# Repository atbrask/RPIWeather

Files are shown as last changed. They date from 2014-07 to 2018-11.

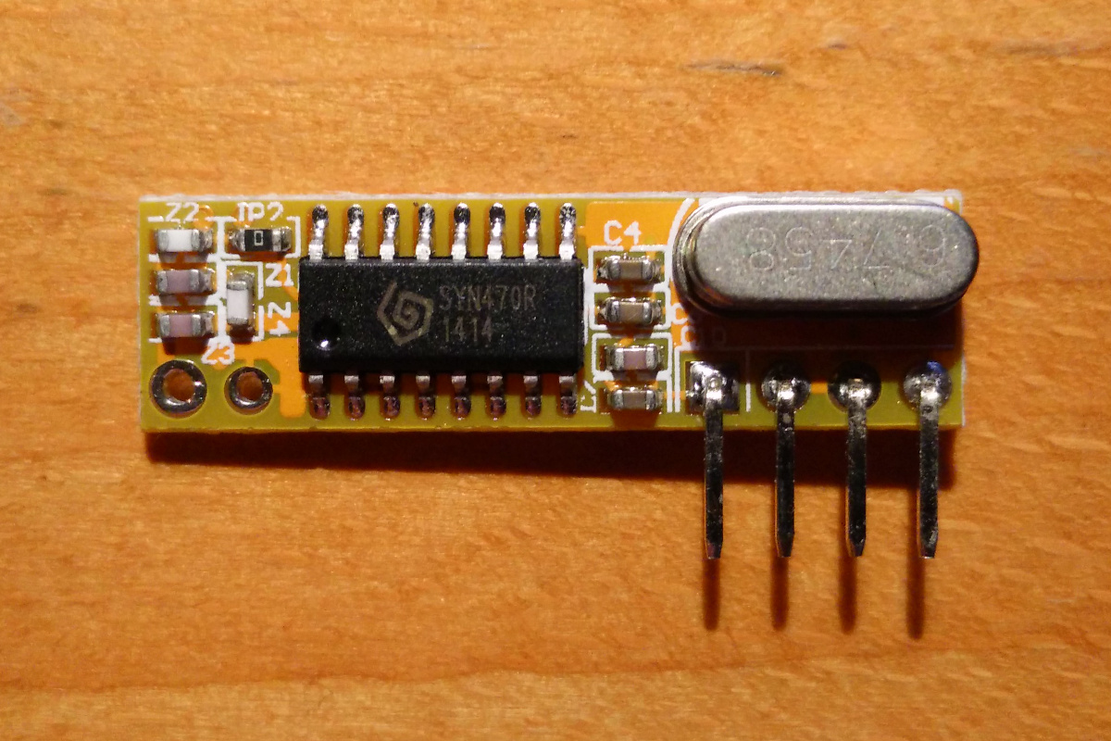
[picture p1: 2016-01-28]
Pictures/RXB12.jpg

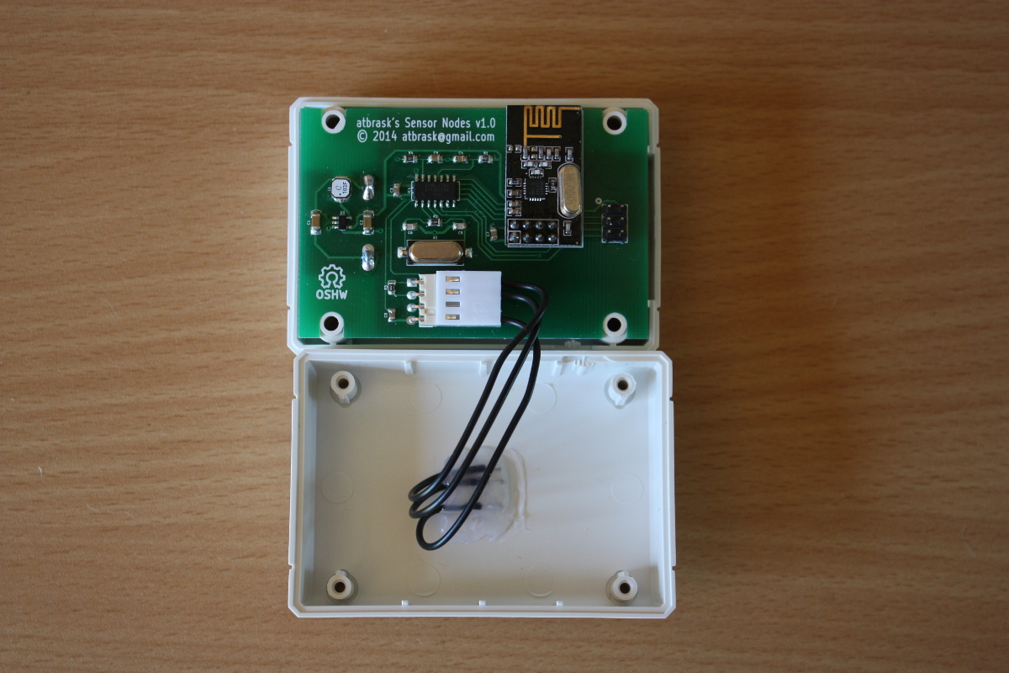
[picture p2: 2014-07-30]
Pictures/node inside.jpg

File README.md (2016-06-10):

## Weather station system based on nRF24L01, DHT22, ATtiny84, ESP8266, Nokia 5110 LCDs, and a Raspberry Pi

### Introduction
This is a complete system for collecting, storing, and displaying environmental
sensor data. The system consists of a number of embedded sensor nodes that
communicate wirelessly with a base station using the very popular nRF24L01
radio modules.

All sensor data is stored in a InfluxDB time-series database. The plan is to
make a couple of display units based on the ESP8266 wifi chip and some Nokia
5110 LCDs. For more thorough analysis a webpage will be implemented too.

In its current form, the project is work-in-progress. Status on the different
parts as of 2016-05-20:

* Node firmware: 100%
* Node hardware: 100%
* Database and backend: 100%
* Display firmware: 10% (LCD library nearly complete)
* Display hardware: 5% (incomplete breadboard prototype)
* Web frontend: 10% (currently a single text page with the latest values)

I have successfully tested concurrent operation of 10 sensor nodes with a DHT22
sensor each. I have prepared a couple more for collecting wind and rain data
as well.

### Sensor node features
* Firmware optimized for ATtiny84 @ 1 MHz (8MHz crystal with the CKDV8 fuse set)
* Temperature and humidity measurement using a DHT22 sensor
* Temperature and humidity measurement using a HTU21D sensor
* Wind speed and wind direction measurement using a La Crosse TX23 anemometer
* Rainfall measurement using a WS-2300-16 rain gauge
* Wireless operation using the very popular nRF24L01+ 2.4 GHz radio chip
* Very compact CRC32 implementation
* Battery powered operation using a very efficient 3.3v DC/DC converter
* Power management by sleeping the CPU and turning off unneeded hardware
* Battery voltage measurement included in data packet
* Typical battery draw while sleeping has been measured to around 17uA
* Total firmware size from 3.0 kiB to 3.5 kiB (depending on sensor type)

Eventually I'll get around to writing a bit about this on my blog at:
http://www.atbrask.dk/

/atbrask

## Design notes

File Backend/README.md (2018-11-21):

### Backend for "atbrask's Sensor Nodes v1.0"
Copyright (c) 2014-2018 A.T.Brask <atbrask@gmail.com> (Except included libs)
All rights reserved

Version history:
* v1.5 (2018-11-21) Upgraded to piCore 9.0.3 and enabled HTTPS support.
* v1.4 (2017-01-16) Upgraded to piCore 8.0 and InfluxDB >=1.0
* v1.3 (2016-01-22) Added support for 433MHz sensors. Lots of refactoring.
* v1.2 (2015-11-11) Fixed compatibility issues
* v1.1 (2015-02-25) Added support for the Bosch BMP085/180 barometric sensor
* v1.0 (2014-10-26) Initial release

This is the backend part of the project. It consists of a gateway server and
an InfluxDB server. The role of the gateway is to fetch data packets from the
sensor nodes and forward them to the database. In case of a database server
crash or reboot (or other availability issues) the gateway will buffer data
until it runs out of memory.

It also supports a Bosch BMP085/180 baremetric sensor connected directly to
the Pi's I2C pins. These measurements are sent to the InfluxDB server just as
the ones from the sensor nodes. Just comment out the relevant lines if you
don't have this sensor installed.

Finally, I have also added support for a few commonly available wireless
433MHz weather station thermometers. This requires a little radio receiver
circuit to be added to the Pi and connected to its on-board UART pins. It
is based around a SYN470 receiver IC and an ATtiny84 MCU. Just comment out
the relevant lines if you don't have this receiver installed.

Installing and configuring InfluxDB is pretty easy, so I'll skip it in this
write-up. Let's then focus on the gateway itself. It's merely a python script
running on a Raspberry Pi with a highly specialized version of Tiny Core Linux
called piCore.

#### Prerequisites
* Raspberry Pi Model B
* SD card
* nRF24L01(+) radio module connected to the SPI bus (see below)
* Optional: BMP085/180 barometric sensor connected to the I2C bus (see below)
* Optional: A 433MHz receiver and a bunch of compatible sensors (see below)
* A bunch of "atbrask's Sensor Nodes"
* A running [InfluxDB](http://influxdb.com) server
* A [disk image of piCore 9.0.3](http://tinycorelinux.net/9.x/armv6/releases/RPi/piCore-9.0.3.zip) (+ basic knowledge about how to use it)
* Knowledge of the python programming language
* An internet connection :-)

#### Connecting an nRF24L01 radio module to the Pi
The Raspberry Pi has a directly accessible SPI bus on the big 26 pin header. I
have connected my radio module as follows. I have not yet experimented with
connecting the IRQ pin. The nRF module is one of the common ones from eBay.
They all seem to have the same 8-pin connector, but double-check it to be sure!

RPi pin | meaning | nRF pin
--------|---------|--------
17      | 3.3v    | 2
19      | MOSI    | 6
20      | GND     | 1
21      | MISO    | 7
22      | CE      | 3
23      | SCLK    | 5
24      | CSN     | 4
??      | IRQ     | 8

#### Connecting a Bosch BMP085/180 barometric sensor module to the Pi
Like the SPI bus above, the Pi has a I2C bus exposed in the same big header.
There are a lot of different BMP085/180 breakout boards out there, so you need
to find out if your board needs 3.3v or 5v, and whether or not you need to add
pull-up resistors to the data pins. I used the fairly well-known GY-68 board.
These can be picked up for $1-2 on Ebay. It has a 3.3v regulator and the
necessary pull-up resistors, so it can be attached directly.

RPi pin | GY-68 pin
--------|----------
3       | SDA
5       | SCL
6       | GND
2       | VCC

If you have a breakout board without the 3.3v regulator, you'll need to use
pin 1 instead of pin 2 for VCC.

#### Connecting a 433MHz receiver to the Pi
I have created a small 433MHz receiver for commonly available weather station
temperature sensors. It is based on a SYN470 receiver IC and an ATtiny84 that 
collects the radio data and forwards it to the Pi. Look elsewhere in this
repository for a schematic and some firmware. The receiver uses the RX pin of
the Pi's on-board UART, so you'll need to disable the serial console that
PiCore exposes on these pins. When this is done, the receiver streams data
to /dev/ttyAMA0 whenever it receives some.

#### Installation
* Install piCore 9.0.3 onto an SD card using `dd` or similar tool.
* Plug in the SD card and boot the Pi.
* Log in to the system using SSH (username `tc` and password `piCore`).
* Change the password to something else using `passwd`.
* Run `filetool.sh -b` to save the newly generated SSH keys.
* Expand the file system (and reboot). See [here](http://www.maketecheasier.com/review-of-picore/) for a how-to.
* When the system is ready, log in again.
* Refresh tcz packages by running `tce-update` followed by a reboot.
* Run `tce-load -wi git` to install git.
* Run `git clone https://www.github.com/atbrask/RPIWeather.git`
* Type `cd RPIWeather/Backend` and run `./install.sh`.
* You can now safely remove the installer code by running `cd ~` followed by `rm -rf RPIWeather`.
* Run `tce-load -wi nano` to install the nano text editor.
* Configure the main RPIWeather script in `/opt/RPIWeather/rpiweather.py` (see details in next section).
* Done! You can reboot if you wish to make sure that everything loads as it should.

If you want to use the 433MHz receiver feature, you'll need a couple of extra steps to free up the on-board UART pins:

* Run `sudo mount /dev/mmcblk0p1`
* Open `/mnt/mmcblk0p1/cmdline.txt` and remove all references `/dev/ttyAMA0`. In my case, I removed `console=ttyAMA0,115200`
* Run `sudo umount /dev/mmcblk0p1`
* Open `/opt/bootlocal.sh`
* Remove or comment out the line `/usr/sbin/startserialtty &`
* Run `sudo filetool.sh -b`to save the changes.
* Reboot

#### Configuration
Now everything is installed and put into the right places. But before running 
the backend, it needs to be configured. 

* Open `/opt/RPIWeather/rpiweather.py` and make the necessary changes. It's a regular python script with some configuration settings. You'll need to put in details about the sensor nodes, how the nRF radio is connected to the Pi, and login details for the InfluxDB server.
* Save your changes.
* Each time you change a setting, run `sudo filetool.sh -b` to persist the changes

#### Running the damn thing
To run the script from the command line write:

    sudo /opt/RPIWeather/rpiweather.py

We need to use `sudo` in order to access the GPIO pins that are connected to
the nRF radio chip and the BMP085/180 sensor.

This is useful for testing the configuration. Remember to check the log file to
see if everything works as expected. But running the gateway from the command
line is impractical for the long run. We need to add it to piCore's list of 
services to be started at boot.

* Open `/opt/bootlocal.sh` and add the line `sudo /opt/RPIWeather/rpiweather.py &`
* Run `sudo filetool.sh -b` to save the changes.
* Reboot to test that it auto-starts

Now the server should be running and ready for use!

#### File locations
* Code entry point: `/opt/RPIWeather/rpiweather.py`
* Log file: `/var/log/rpiweather.log`

That is all! Have fun hacking!

/atbrask

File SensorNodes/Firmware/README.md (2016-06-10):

### Firmware for "atbrask's Sensor Nodes v1.0"
Copyright (c) 2014-2016 A.T.Brask <atbrask@gmail.com> (Except 3rd party libraries)
All rights reserved

Version history:
* v1.0 (2014-04-26) First finished version supporting the DHT22 thermo/hygrometer
* v1.1 (2014-06-08) Added support for the La Crosse TX23 anemometer
* v1.2 (2014-07-25) Added support for the WS-2300-16 rain gauge
* v1.3 (2014-07-30) Fixed a lot of small issues
* v1.4 (2014-10-17) Fixed a few engineering units
* V1.5 (2016-05-20) Added support for the HTU21D thermo/hygrometer

Please note that the code uses a few C++11 features. It might not work with
older versions of avr-gcc.

Set correct fuses:

    make fuses

Read back fuses:

    make rdfuses

Rebuild code for unit 01:02 with VCC = 3.32v and a DHT22 sensor on board:

    make rebuild UNITID=0x0102 VCC=3320 SENSORTYPE=DHT22

The default build rule rebuilds the firmware and attempts to flash the device:

    make UNITID=0x0102 VCC=3320 SENSORTYPE=DHT22

Possible values for SENSORTYPE:
* DHT22 - Temperature/humidity sensor
* TX23 - Anemometer (wind speed and wind direction)
* WS_2300_16 - Rain gauge
* HTU21D - Temperature/humidity sensor

In order to use I2C sensors (i.e. the HTU21D) you'll need to desolder R3 and
C8 as well as add a wire from 3.3V to the spare pin of the 4-pin connector.
When this is done, the 4-pin connector will have the following pinout:

Pin | Meaning
----|--------
1   | SDA
2   | SCL
3   | 3.3V
4   | GND

You can get the most recent version of this code and all the schematics at:
https://www.github.com/atbrask/RPIWeather/

Eventually I'll get around to writing a bit about this on my blog at:
http://www.atbrask.dk/

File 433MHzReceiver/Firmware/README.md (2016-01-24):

### Firmware to "433MHz Receiver v1.0"
Copyright (c) 2016 A.T.Brask <atbrask@gmail.com> (Except BasicSerial3)
All rights reserved

Version history:
* v1.0 (2016-01-24) Initial release

You can get the most recent version of this code and all the schematics at:
https://www.github.com/atbrask/RPIWeather/

Eventually I'll get around to writing a bit about this on my blog at:
http://www.atbrask.dk/

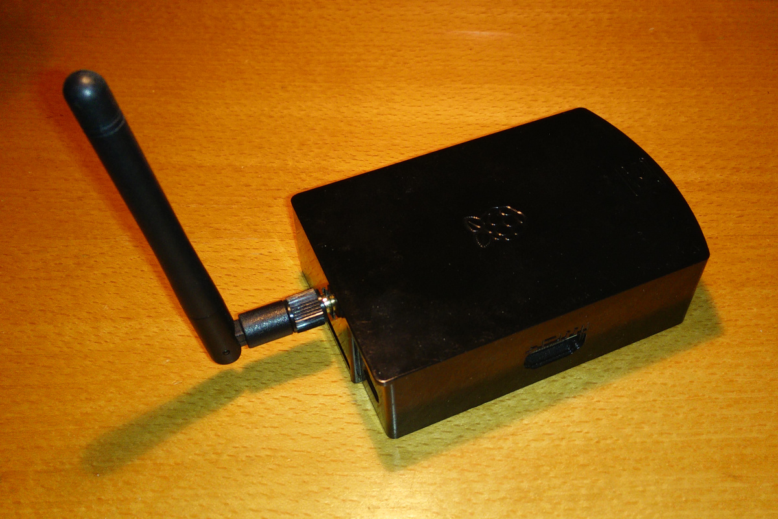
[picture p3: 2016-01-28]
Pictures/RPIWeatherBasestation.jpg

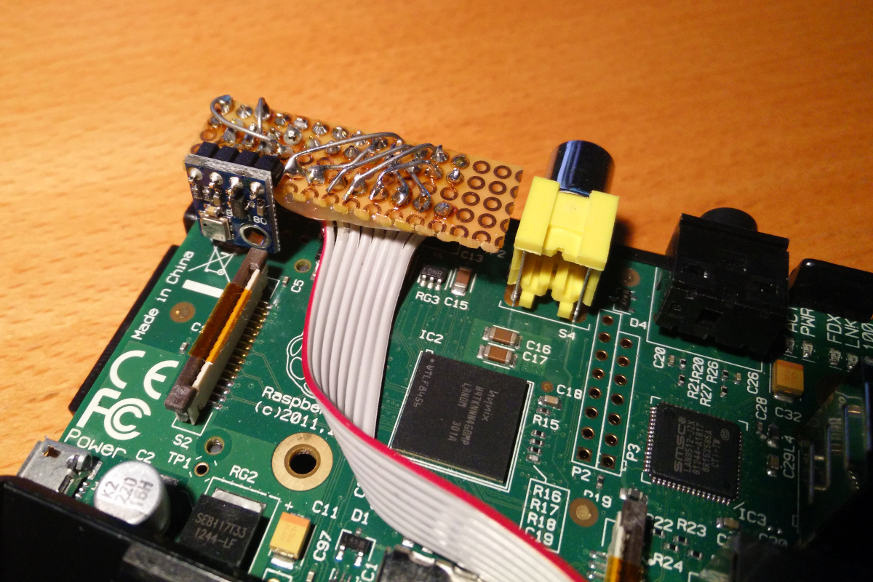
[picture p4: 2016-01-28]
Pictures/HeaderCloseup.jpg

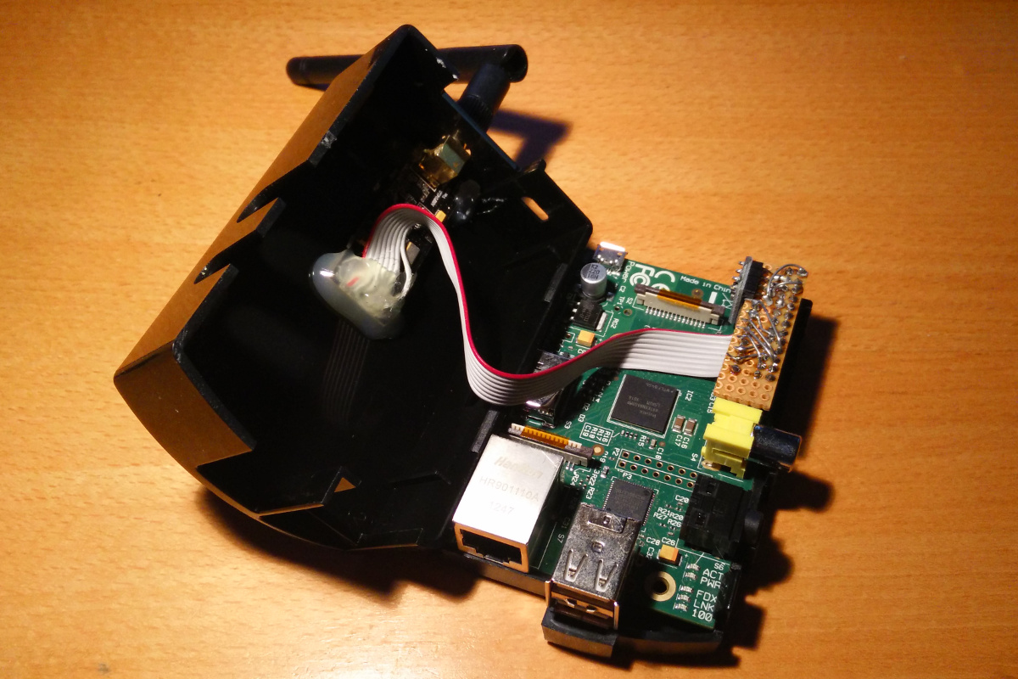
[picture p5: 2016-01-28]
Pictures/RPIWeatherInside.jpg

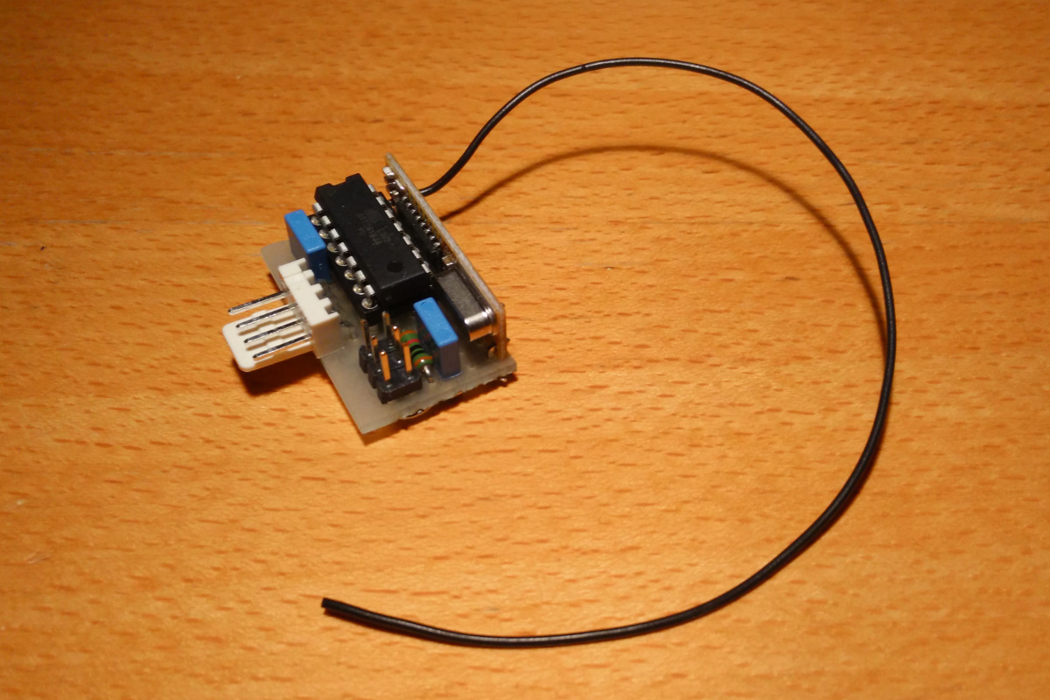
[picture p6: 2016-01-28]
Pictures/433MHzReceiverTop.jpg

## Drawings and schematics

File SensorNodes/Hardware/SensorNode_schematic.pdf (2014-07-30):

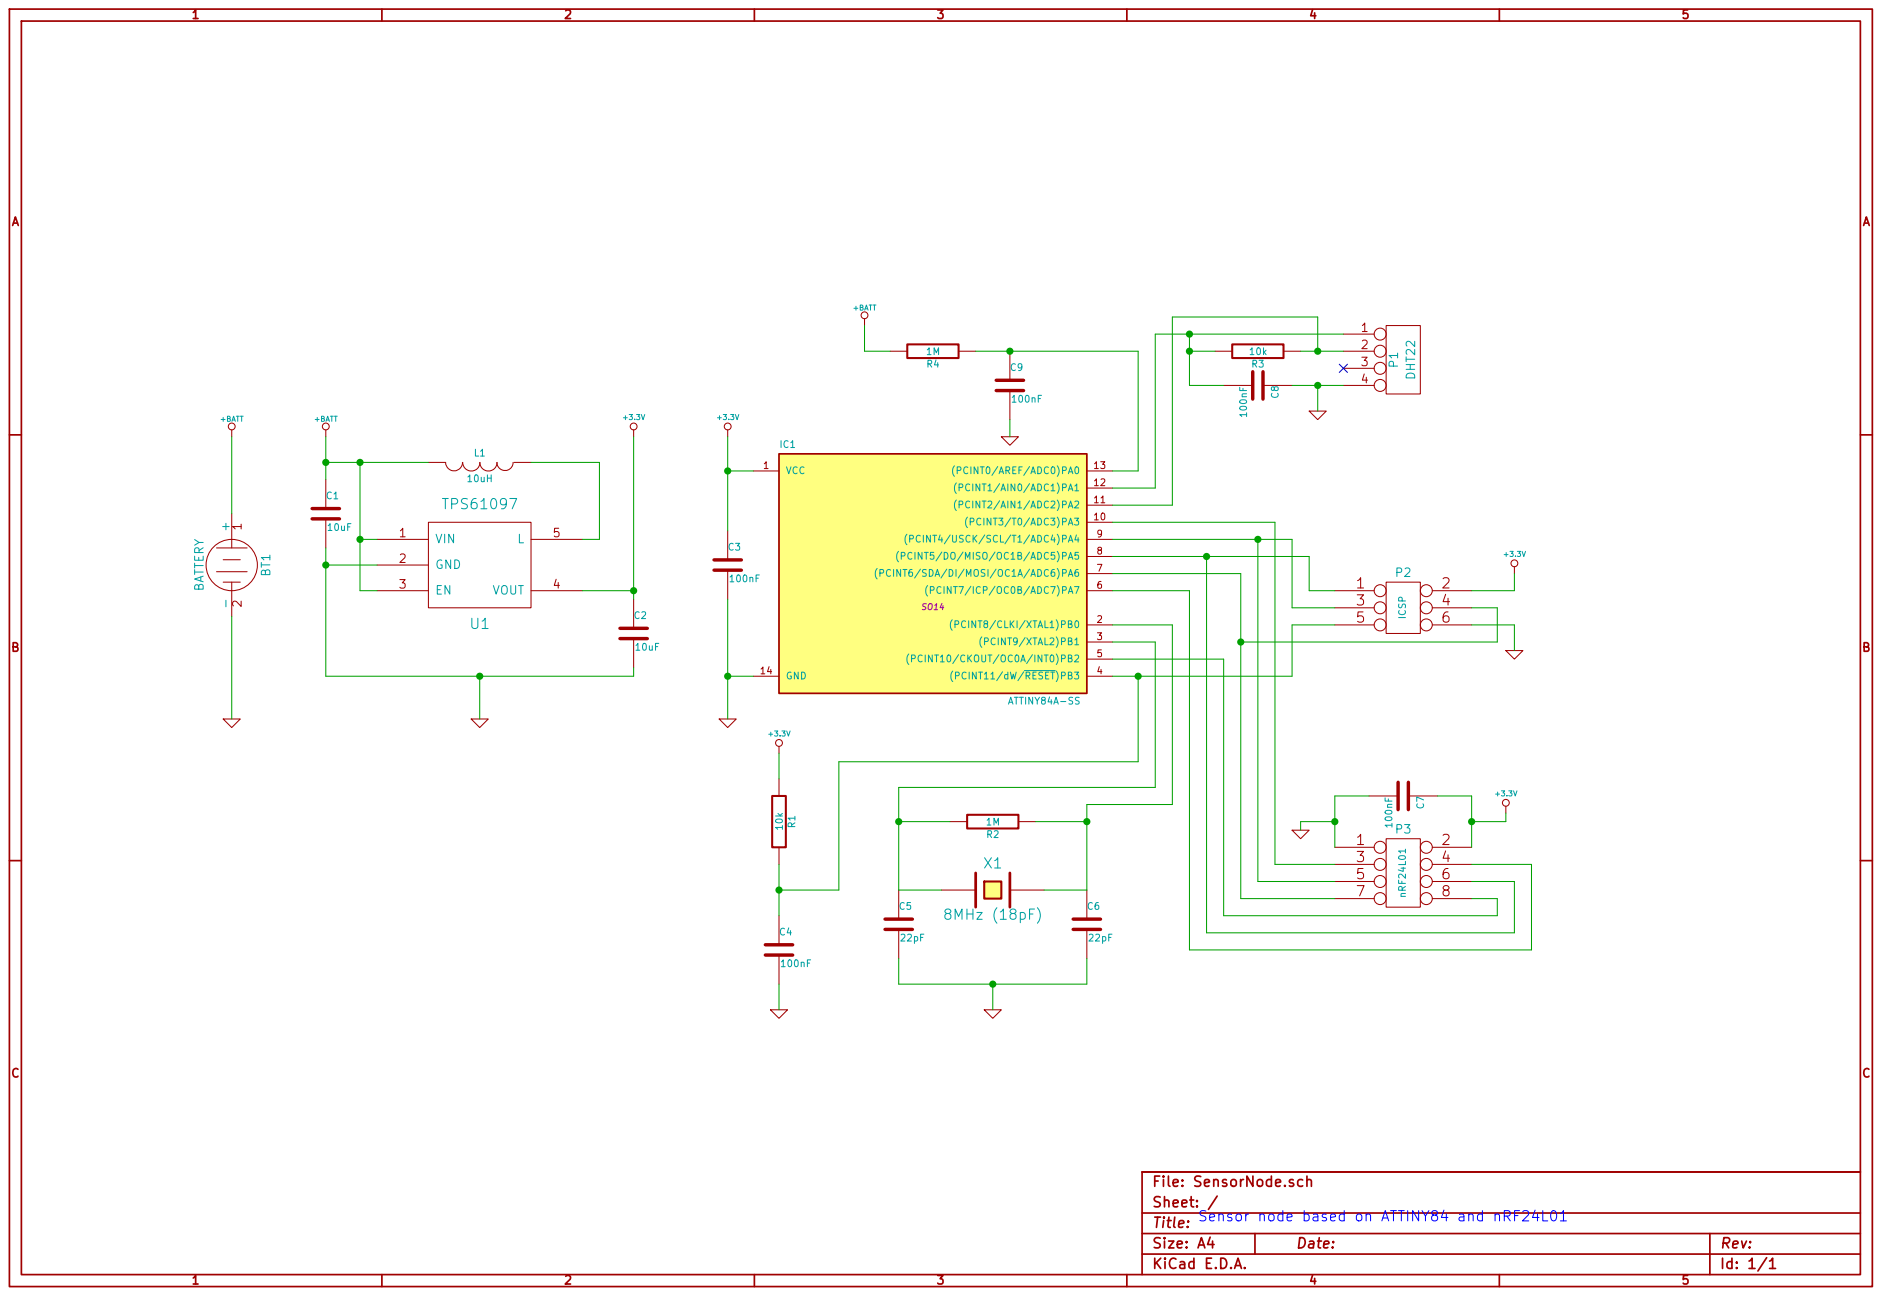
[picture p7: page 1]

Id: 1/1 Title: File: SensorNode.sch
Sheet: /
Sensor node based on ATTINY84 and nRF24L01

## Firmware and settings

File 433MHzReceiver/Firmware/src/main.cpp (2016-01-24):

/*
Firmware to "433MHz Receiver v1.0"
Copyright (c) 2016 A.T.Brask <atbrask@gmail.com>

This program is free software; you can redistribute it and/or modify it under
the terms of the GNU General Public License as published by the Free Software
Foundation; either version 2 of the License, or (at your option) any later
version.
This program is distributed in the hope that it will be useful, but WITHOUT 
ANY WARRANTY; without even the implied warranty of MERCHANTABILITY or FITNESS 
FOR A PARTICULAR PURPOSE. See the GNU General Public License for more details.
You should have received a copy of the GNU General Public License along with
this program; if not, write to the Free Software Foundation, Inc., 
59 Temple Place, Suite 330, Boston, MA 02111-1307 USA
*/

#include <avr/io.h>
#include <avr/interrupt.h>
#include <stdint.h>

#include "BasicSerial3.h"
#include "TX3Decoder.h"
#include "ChinaDecoder.h"
#include "OregonV1Decoder.h"
#include "OregonV2Decoder.h"
#include "CRC32.h"

// GLOBAL VARIABLES

TX3Decoder tx3;
ChinaDecoder china;
OregonV1Decoder orscV1;
OregonV2Decoder orscV2;

volatile uint16_t pulse;
volatile uint16_t micros;
volatile bool pinstate;

// SERIAL OUTPUT

void writeString(const char* str)
{
   while (*str)
    TxByte (*str++);
}

void writeHexNibble(uint8_t nibble)
{
    nibble &= 0xf;
    if (nibble < 10)
        TxByte(nibble+48); // 0...9
    else
        TxByte(nibble+55); // A...F
}

void writeHexByte(uint8_t byte)
{
    writeHexNibble(byte >> 4);
    writeHexNibble(byte & 0xf);
}

void writeSerial(BaseDecoder& decoder) 
{
    uint8_t data[25];
    uint8_t length = decoder.getData(data);
    uint32_t crc = CRC32::calculate((uint8_t*)&data, length);

    // Write decoder name
    writeString(decoder.getName());
    TxByte(' ');

    // Write received data
    for (uint8_t i = 0; i < length; ++i)
        writeHexByte(data[i]);
    TxByte(' ');

    // Write CRC32
    writeHexByte((uint8_t)((crc >> 24) & 0xff));
    writeHexByte((uint8_t)((crc >> 16) & 0xff));
    writeHexByte((uint8_t)((crc >> 8) & 0xff));
    writeHexByte((uint8_t)(crc & 0xff));

    TxByte('\n');
    
    decoder.reset();
}

// RADIO INPUT

void initRadioListener()
{
    // Set up listener interrupt on PA2
    DDRA &= ~_BV(PA2);     // Set ADC1 (pin 12) as input
    PORTA |= _BV(PA2);     // Enable pull-up
    PCMSK0 |= _BV(PCINT2); // Pin change mask: listen to PA2 
    GIMSK |= _BV(PCIE0);   // Enable PCINT interrupt 
}

ISR(PCINT0_vect)
{
    static uint16_t last;
    pulse = micros - last;
    last += pulse;
    pinstate = !(PINA & _BV(PA2));
}

// TIMER

void initTimer()
{
    // Set up timer 0
    TCCR0A = _BV(WGM01);   // CTC mode
    TCCR0B = _BV(CS01);    // Div8
    OCR0A = 49;            // 50us compare value
    TIMSK0 |= _BV(OCIE0A); // Enable timer interrupt
}

ISR (TIM0_COMPA_vect)
{
    micros+=50;
}

// MAIN

int main()
{
    writeString("[433MHzReceiver]\n");

    initRadioListener();
    initTimer();

    while(true)
    {
        cli();
        uint16_t p = pulse;
        pulse = 0;
        bool s = pinstate;
        sei();
    
        if (p != 0) 
        {
            if (tx3.decode(p, s))
                writeSerial(tx3);
            if (china.decode(p, s))
                writeSerial(china);
            if (orscV1.decode(p, s))
                writeSerial(orscV1);  
            if (orscV2.decode(p, s))
                writeSerial(orscV2);  
        }
    }
}

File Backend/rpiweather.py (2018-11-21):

#!/usr/bin/python

# RPIWeather Data Gateway
# Copyright (c) 2014-2018 A.T.Brask <atbrask@gmail.com>
#
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
import time
import logging
import logging.handlers
import Queue

from RPIWeather import InfluxDBSender
from RPIWeather import OOK433MHzReceiver
from RPIWeather import BMPSampler
from RPIWeather import RF24Receiver

if __name__ == "__main__":

    #################
    # CONFIGURATION #
    #################

    # RF24 receiver settings
    spiMajor    = 0
    spiMinor    = 0
    cePin       = 25 #GPIO25 = pin 22
    irqPin      = 24 #GPIO24 = pin 18
    readPipe    = [0x01, 0x28, 0x09, 0x13, 0x20]
    writePipe   = [0x02, 0x28, 0x09, 0x13, 0x20]
    channel     = 0x5c
    magicnumber = 0x20130928

    # Database settings
    host       = "192.168.1.251"
    port       = 8086
    ssl        = False
    verify_ssl = False
    username   = "gateway"
    password   = "thomas"
    database   = "RPIWeather"
    table      = "sensordata"

    # 433 MHz receiver settings
    serialPort = '/dev/ttyAMA0'

    # BMP085/180 pressure sensor settings
    bmpSampleInterval   = 300 # seconds
    heightAboveSeaLevel = 24  # meters

    # Logging configuration
    logFileName = "/var/log/rpiweather.log"
    maxBytes    = 1048576
    backupCount = 5

    # Mapping from IDs to names
    namemap = {"BMP":       "Sensor-0001",

               "RF24-0101": "Sensor-0101",
               "RF24-0102": "Sensor-0102",
               "RF24-0103": "Sensor-0103",
               "RF24-0104": "Sensor-0104",
               "RF24-0105": "Sensor-0105",
               "RF24-0106": "Sensor-0106",
               "RF24-0107": "Sensor-0107",
               "RF24-0108": "Sensor-0108",
               "RF24-0109": "Sensor-0109",
               "RF24-010A": "Sensor-010A",
               "RF24-010B": "Sensor-010B",

               "RF24-FFFF": "Sensor-FFFF", # reserved for debugging

               "OS1-08-2":  "Sensor-0201",
               "TX3-10":    "Sensor-0202",
               "CHN-10":    "Sensor-0203",
               "OS2-22-2":  "Sensor-0204"}

    #########
    # START #
    #########

    # Start logging
    logger = logging.getLogger("RPIWeather")
    logger.setLevel(logging.DEBUG)
    handler = logging.handlers.RotatingFileHandler(logFileName, maxBytes=maxBytes, backupCount=backupCount)
    formatter = logging.Formatter('%(asctime)s - %(levelname)s - %(message)s')
    handler.setFormatter(formatter)
    logger.addHandler(handler)

    logger.info("RPIWeather Data Gateway (c) 2014-2018 atbrask")

    # Start data queue
    dataqueue = Queue.Queue()

    # Start data receivers
    RF24Receiver.RF24Receiver(spiMajor, spiMinor, cePin, irqPin, channel, writePipe, readPipe, magicnumber, dataqueue, logger).start()
    OOK433MHzReceiver.OOK433MHzReceiver(serialPort, dataqueue, logger).start()
    BMPSampler.BMPSampler(bmpSampleInterval, heightAboveSeaLevel, dataqueue, logger).start()

    # Start data sender
    InfluxDBSender.InfluxDBSender(host, port, ssl, verify_ssl, username, password, database, table, namemap, dataqueue, logger).start()

    # Wait forever
    logger.info("RPIWeather Data Gateway start-up completed!")
    while(True):
        time.sleep(5)

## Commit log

2014-07-30 Added PDF of schematic
2014-07-31 Added firmware for sensor nodes (sans the RF24 library)
2014-10-17 Changed some units. Now all sensors operate with one decimal of precision.
2014-10-26 Fixed a couple of things in the install script
2014-12-30 Updated a couple of READMEs
2014-12-30 Changed folder structure to prepare for another firmware/hardware sub project.
    [SensorNode.brd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]
2015-11-07 Changed pin numbers from BOARD to BCM
2015-11-11 Fixed pynrf24 compatibility stuff
    Fixed the available() call to be compatible with the current version of pynrf24.
    Reversed pipe byte order to be compatible with the current version of pynrf24.
    [rpiweather.py]
2016-01-22 Added support for 433MHz sensors. Lots of refactoring.
2016-01-26 Added 433MHz receiver KiCad schematic
    [433MHzReceiver.sch]
2016-06-10 Added support for HTU21D temp/hum sensors
2016-06-14 Added another sensor id
2017-06-17 Fixed not checking the calculated CRC8
    [OOK433MHzReceiver.py]
2021-02-20 Updated rain sensor code.
